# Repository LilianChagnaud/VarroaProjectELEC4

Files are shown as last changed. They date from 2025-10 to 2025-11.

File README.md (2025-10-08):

Projet
2 : comptage de varroa  (effectif : 4)
> sujet existant à compléter :
> https://filesender.renater.fr/?s=download&token=6d0fe1de-e8f5-43eb-b47a-897a4730366f
> - finaliser la partie mécanique
> - valider le choix de la caméra
> - développer la reconnaissance d'image
> - développer l'IHM

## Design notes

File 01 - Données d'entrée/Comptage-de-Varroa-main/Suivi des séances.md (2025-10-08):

### 1ère séance

Au cours de la première séance, nous avons choisi de travailler sur le projet "Comptage de Varroa".
Nous avons entamé la rédaction du cahier des charges pour définir les éléments essentiels du projet.

Afin de visualiser les varroas sur une feuille, nous avons a notre disposition l'ESP32-CAM.
Nous avons alors tenté de visualiser une photo capturée par la caméra de l’ESP32-CAM.
Pour cela, nous avons utilisé le logiciel Arduino IDE pour nous connecter à l’ESP32-CAM.
Nous avons installé Arduino IDE afin de configurer et accéder à la caméra.
Un programme Arduino a été développé pour permettre cette interaction.
La caméra intègre un serveur web, ce qui nous permet de visualiser les photos directement en ligne grâce à l'adresse IP.

Voici le code pour visualiser les photos sur un serveur web : 

```c++
#include "esp_camera.h"
#include <WiFi.h>
#include "WebServer.h"
#include "esp_http_server.h" 

const char* ssid = "Pixel_3581";
const char* password = "12345678910";

#define PWDN_GPIO_NUM 32
#define RESET_GPIO_NUM -1
#define XCLK_GPIO_NUM 0
#define SIOD_GPIO_NUM 26
#define SIOC_GPIO_NUM 27
#define Y9_GPIO_NUM 35
#define Y8_GPIO_NUM 34
#define Y7_GPIO_NUM 39
#define Y6_GPIO_NUM 36
#define Y5_GPIO_NUM 21
#define Y4_GPIO_NUM 19
#define Y3_GPIO_NUM 18
#define Y2_GPIO_NUM 5
#define VSYNC_GPIO_NUM 25
#define HREF_GPIO_NUM 23
#define PCLK_GPIO_NUM 22

void startCameraServer();
void setup() {
Serial.begin(115200);
Serial.setDebugOutput(true);
Serial.println(); 

// Configuration de la caméra
camera_config_t config;
config.ledc_channel = LEDC_CHANNEL_0;
config.ledc_timer = LEDC_TIMER_0;
config.pin_d0 = Y2_GPIO_NUM;
config.pin_d1 = Y3_GPIO_NUM;
config.pin_d2 = Y4_GPIO_NUM;
config.pin_d3 = Y5_GPIO_NUM;
config.pin_d4 = Y6_GPIO_NUM;
config.pin_d5 = Y7_GPIO_NUM;
config.pin_d6 = Y8_GPIO_NUM;
config.pin_d7 = Y9_GPIO_NUM;
config.pin_xclk = XCLK_GPIO_NUM;
config.pin_pclk = PCLK_GPIO_NUM;
config.pin_vsync = VSYNC_GPIO_NUM;
config.pin_href = HREF_GPIO_NUM;
config.pin_sscb_sda = SIOD_GPIO_NUM;
config.pin_sscb_scl = SIOC_GPIO_NUM;
config.pin_pwdn = PWDN_GPIO_NUM;
config.pin_reset = RESET_GPIO_NUM;
config.xclk_freq_hz = 20000000;
config.pixel_format = PIXFORMAT_JPEG;

if(psramFound()){
	config.frame_size = FRAMESIZE_UXGA;
	config.jpeg_quality = 10;
	config.fb_count = 2;
} else {
	config.frame_size = FRAMESIZE_SVGA;
	config.jpeg_quality = 12;
	config.fb_count = 1;
}

// Initialisation de la caméra
esp_err_t err = esp_camera_init(&config);
if (err != ESP_OK) {
	Serial.printf("Échec d'initialisation de la caméra, erreur 0x%x", err);
return;
}

// Connexion Wi-Fi
WiFi.begin(ssid, password);
while (WiFi.status() != WL_CONNECTED) {
	delay(500);
	Serial.print(WiFi.status());
}

Serial.println("");
Serial.println("Connexion Wi-Fi établie");
Serial.print("Adresse IP : ");
Serial.println(WiFi.localIP());

// Démarrage du serveur de caméra
startCameraServer();
Serial.println("Serveur caméra démarré");
}
void loop() {
	delay(10000);
}

// Définition de la fonction startCameraServer et stream_handler
httpd_handle_t stream_httpd = NULL;
static esp_err_t stream_handler(httpd_req_t *req){
camera_fb_t * fb = NULL;
esp_err_t res = ESP_OK;
size_t _jpg_buf_len = 0;
uint8_t * _jpg_buf = NULL;
fb = esp_camera_fb_get();

if (!fb) {
	Serial.println("Échec de capture de la frame");
	httpd_resp_send_500(req);
	return ESP_FAIL;
}

if(fb->format != PIXFORMAT_JPEG){
	bool jpeg_converted = frame2jpg(fb, 80, &_jpg_buf, &_jpg_buf_len);
if(!jpeg_converted){
	Serial.println("Échec de la compression JPEG");
	esp_camera_fb_return(fb);
	httpd_resp_send_500(req);
	return ESP_FAIL;
}

} else {
	_jpg_buf_len = fb->len;
	_jpg_buf = fb->buf;
}

httpd_resp_set_type(req, "image/jpeg");
res = httpd_resp_send(req, (const char *)_jpg_buf, _jpg_buf_len);
if(fb->format != PIXFORMAT_JPEG){
	free(_jpg_buf);
}
	esp_camera_fb_return(fb);
	return res;
}

void startCameraServer(){
	httpd_config_t config = HTTPD_DEFAULT_CONFIG();
	config.server_port = 80;
	httpd_uri_t stream_uri = {
	.uri = "/",
	.method = HTTP_GET,
	.handler = stream_handler,
	.user_ctx = NULL
};

if (httpd_start(&stream_httpd, &config) == ESP_OK) {
	httpd_register_uri_handler(stream_httpd, &stream_uri);
}
}
```

### 2ème séance

Au cours de la deuxième séance, nous avons tenté de faire fonctionner le moteur.
Celui-ci est contrôlé par un microcontrôleur LoRa WiFi et un driver TMC2226.

Nous avons effectué le câblage nécessaire pour assurer la commande du moteur :

-------------------------------------------------------------------------------------------------------------

Câblage Moteur

-------------------------------------------------------------------------------------------------------------

Ainsi que le programme Arduino :

```c++
const int Pas = 18;
const int Dir = 19;

void setup() {
	Serial.begin(115200);
	pinMode(Pas, OUTPUT);
	pinMode(Dir, OUTPUT);
	digitalWrite(Dir, HIGH); // Vous pouvez changer à LOW si vous voulez que le moteur tourne dans l'autre sens
}
void loop() {
	for(int x=0; x<200; x++){
	digitalWrite(Pas, HIGH);
	delayMicroseconds(500); // Ajustez le délai pour contrôler la vitesse
	digitalWrite(Pas, LOW);
	delay(4);
}
delay(1000);
}
```

### 3ème séance

Au cours de la troisième séance, nous travaillons toujours sur le fonctionnement du moteur.
Après avoir constaté un problème avec le driver initial, nous l’avons remplacé par un autre.
Nous avons également opté pour un moteur 12V afin de poursuivre nos essais.
Des tests ont été réalisés avec le driver A4988, mais ils se sont révélés infructueux.
Nous sommes donc revenus à l’utilisation du TMC2226 pour continuer nos essais.

Voici le code pour faire tourner le moteur dans les deux sens :

```c++ 
const int Pas = 3;
const int Dir = 2;
void setup() {
  Serial.begin(115200);
  pinMode(Pas, OUTPUT);
  pinMode(Dir, OUTPUT);
  digitalWrite(Dir, HIGH);
}
void loop() {

  for (int x = 200; x > 0; x--) {
    Serial.println(x);
    digitalWrite(Dir, LOW);
    digitalWrite(Pas, HIGH);
    delayMicroseconds(500);
    digitalWrite(Pas, LOW);
    delay(4);}
 
  for (int x = 0; x < 200; x++) {
    Serial.println(x);    
    digitalWrite(Dir, HIGH);
    digitalWrite(Pas, HIGH);
    delayMicroseconds(500);
    digitalWrite(Pas, LOW);
    delay(4);
  }
  delay(2000);
}
```

### 4ème séance

Après de nombreux essais sur les moteurs, il semble que le problème provienne des alimentations plutôt que du câblage ou du programme.
Le professeur nous a alors suggéré d’utiliser une alimentation 12V via une prise secteur adaptée.

Nous avons ensuite déterminé la hauteur optimale pour positionner la caméra afin d'obtenir une image nette et claire. Cette hauteur est de 24 cm. 

-------------------------------------------------------------------------------------------------------------

Capture d’écran 2024-11-25 à 16 32 52

-------------------------------------------------------------------------------------------------------------

Nous utiliserons cette référence pour créer notre programme 3D.
Pour visualiser le projet, j'ai commencé à créer la conception assistée par ordinateur (CAO) :

-------------------------------------------------------------------------------------------------------------

Capture d’écran 2024-11-25 à 16 59 09

-------------------------------------------------------------------------------------------------------------

### 5ème séance

Au cours de ma cinquième séance de travail, ma priorité était la conception d'un système mécanique de déplacement de caméra en 3D, en utilisant le logiciel de conception assistée par ordinateur Fusion 360. Cela nous permettra d'avoir une vision global du projet, afin de réaliser la partie mécanique de celui-ci.

-------------------------------------------------------------------------------------------------------------

Capture d’écran 2024-11-26 à 11 46 03

-------------------------------------------------------------------------------------------------------------

Le dispositif mécanique que j'ai développé comprend plusieurs éléments :

- Un moteur pas à pas connecté à un axe cylindrique via un coupleur
- Un roulement intégré sur l'axe pour garantir une rotation stable et guidée
- Une transmission du mouvement rotatif permettant le déplacement de la caméra
- Une structure verticale composée de montants supportant l'axe

J'ai stratégiquement positionné les axes à une hauteur de 24 cm, ce qui permet :

- De surélever la caméra au maximum
- D'améliorer la qualité de l'image
- D'élargir significativement le champ de vision

L'axe traversant la structure servira à la fois de guide et de support pour le système de déplacement.

-------------------------------------------------------------------------------------------------------------

Capture d’écran 2024-12-08 à 14 12 38

-------------------------------------------------------------------------------------------------------------

Le dispositif mécanique que j'ai développé comprend plusieurs éléments :

- Un moteur pas à pas connecté à un axe cylindrique via un coupleur
- Un roulement intégré sur l'axe pour garantir une rotation stable et guidée
- Une transmission du mouvement rotatif permettant le déplacement de la caméra
- Une structure verticale composée de montants supportant l'axe

J'ai stratégiquement positionné les axes à une hauteur de 24 cm, ce qui permet :

- De surélever la caméra au maximum
- D'améliorer la qualité de l'image
- D'élargir significativement le champ de vision

-------------------------------------------------------------------------------------------------------------

Capture d’écran 2024-12-08 à 14 14 22

-------------------------------------------------------------------------------------------------------------

L'axe traversant la structure servira à la fois de guide et de support pour le système de déplacement.

-------------------------------------------------------------------------------------------------------------

Capture d’écran 2024-12-08 à 14 06 52

-------------------------------------------------------------------------------------------------------------

Ici, nous observons la section où se situe le support de la caméra. Elle comprend deux supports montés sur des roulements à billes, permettant un mouvement horizontal, ainsi qu’un support également monté sur des roulements à billes, offrant un mouvement vertical.

-------------------------------------------------------------------------------------------------------------

Capture d’écran 2024-12-08 à 14 09 39

-------------------------------------------------------------------------------------------------------------

Suite aux retours de Monsieur Peter et d’un professeur de robotique concernant ma modélisation 3D, plusieurs points d’amélioration ont été soulevés :
- Remplacer le roulement cranté par un roulement à billes.
- Positionner les moteurs du même côté pour faciliter le cheminement des câbles.
- Supprimer le roulement au niveau de la plateforme supportant la caméra et le remplacer par un système de pincement au support.
- Ajouter des guides pour le câblage.
- Réduire l’épaisseur de la plateforme afin de limiter l’inertie et alléger l’ensemble.
- Concevoir des blocs empilables pour les pylônes.
- Remplacer les pièces de glissement des plateformes par des pièces usinées.
- Intégrer des fins de course.

**Remplacer le roulement cranté par un roulement à billes :**

-------------------------------------------------------------------------------------------------------------

Capture d’écran 2024-12-09 à 11 58 18

-------------------------------------------------------------------------------------------------------------

**Moteurs du même coté :**

-------------------------------------------------------------------------------------------------------------

Capture d’écran 2024-12-09 à 11 55 22

-------------------------------------------------------------------------------------------------------------

**Système de pincement :**

-------------------------------------------------------------------------------------------------------------

Capture d’écran 2024-12-09 à 11 59 41

-------------------------------------------------------------------------------------------------------------

**Ajout capteur de fin de course :**

-------------------------------------------------------------------------------------------------------------

Capture d’écran 2024-12-09 à 15 05 34

-------------------------------------------------------------------------------------------------------------

### 6ème séances

Lors de la 6ᵉ séance, j'ai pris les mesures exactes nécessaires pour modéliser les pièces en 3D en vue de leur impression. Pour le moment, les pièces imprimées serviront de prototypes afin de valider les dimensions.

#### Côtes

- [i] Flexible couplings moteur : 18,50 mm de diamètre

- [i] Moteur :
	- [>] Axe moteur : 5 mm
	- [>] Largeur moteur : 42 mm
	- [>] Longueur moteur : 39,5 mm

- [i] Axes profilés :
	- [>] Diamètre 8 mm

- [i] Roulement :
	- [>] Diamètre de 22 mm 

- [i] Support Axes :
	- [>] Longueur : 30 mm
	- [>] Hauteur : 22 mm
	- [>] Largeur : 33,9 mm

- [?] Prévoir support pour fixer le moteur  

#### Impression

- [x] Pylone à gauche du moteur
- [ ] Pylone à droite du moteur
- [ ] Pylone en parallèle du moteur
- [ ] Pylone moteur
- [ ] Support axe moteur 
- [ ] Support axe
- [ ] Support camera

### 7ème séances

Lors de la 7ᵉ séance, j’ai imprimé les prototypes afin de valider les pièces et de pouvoir enfin lancer les impressions finales pour assembler l’ensemble du projet. Les prototypes se sont avérés concluants.







### 8ème séances

Lors de cette séance, j’ai assemblé les prototypes afin de préparer l’impression des pièces finales. J’ai également programmé la gestion des moteurs, en intégrant des capteurs de fin de course et un bouton poussoir permettant d’arrêter le système à tout moment. Après quelques ajustements, j’ai modifié les prototypes pour ajouter les emplacements nécessaires aux capteurs.

Images/Capture d’écran 2025-04-26 à 15.20.42.png

Images/Capture d’écran 2025-04-26 à 15.21.03.png

### 9ème séances

Pendant la 9ᵉ séance, avec Jack, nous avons découpé la plaque de bois qui servira de support pour le système. Nous avons positionné l’ensemble sur la plaque et percé les quatre coins pour installer les supports. Ensuite, nous avons pris différentes mesures entre les piliers pour déterminer les longueurs de profilés à découper. Nous avons également remarqué qu’il était nécessaire de prévoir des fixations supplémentaires sur certaines pièces pour pouvoir attacher correctement les courroies.

Images/Capture d’écran 2025-04-26 à 15.21.19.png

### 10ème séances

Lors de cette séance, j’ai réalisé toutes les modifications 3D nécessaires afin de pouvoir enfin imprimer les pièces et monter le système complet. Un nouveau projet Fusion a aussi été créé pour prendre en compte les cotes réelles du montage.

Images/Capture d’écran 2025-04-26 à 15.21.55.png

### 11ème séances

Durant la 11ᵉ séance, nous avons découpé les profilés à la bonne longueur.

/Users/kylianyacoub/Downloads/Capture d’écran 2025-04-26 à 15.22.17.png

Nous avons ensuite assemblé l’ensemble du système, en effectuant les derniers réglages mécaniques pour tout finaliser.

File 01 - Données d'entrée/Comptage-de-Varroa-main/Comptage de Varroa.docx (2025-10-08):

PROJET : COMPTAGE DE VARROA

Outils à disposition :

- ESP32-CAM
- Support caméra
- Feuille (460-380)
- Moteur pas à pas
- Roulement
- LCD
- Courroies
- Alimentation moteur

https://users.polytech.unice.fr/~pmasson/Enseignement-arduino.htm

https://github.com/makerbase-mks/MKS-StepStick-Driver

Suivie des séances :

1er cours : Nous avons essayé de visualiser une photo prise par la caméra.
Nous nous sommes connectés au ESP32-CAM grâce au logiciel Arduino IDE. Installation de Arduino IDE pour accéder à la caméra du ESP32-CAM. La caméra possède un serveur web ou nous pouvons ainsi visualiser les photos prises par la caméra.

Nous avons également commencé le cahier des charges afin de définir les points importants du projet.

2ème cours :

Cahier des charges : Projet de comptage des varroas

Voici un cahier des charges détaillé pour le projet de comptage des varroas. Ce document formalisera les objectifs, contraintes et besoins spécifiques du projet et servira de référence tout au long de la réalisation.

1. Contexte et objectif

Le varroa est un parasite qui affaiblit les colonies d’abeilles en se nourrissant de leur hémolymphe. Le projet a pour objectif de développer un système de comptage des varroas automatique et à faible coût, basé sur l'utilisation d'une caméra et d'un microcontrôleur ESP32-CAM. Une feuille de papier sera placée sous la ruche pour collecter les varroas qui y tombent. Un système de reconnaissance sera mis en place à l'aide d'une caméra montée sur des axes motorisés, permettant de balayer l'intégralité de la feuille et de détecter les varroas recueillis.

2. Fonctionnalités principales

- Détection et comptage des varroas : Le système doit être capable d’identifier les varroas sur une feuille et de les compter avec précision.
- Stockage ou transmission des données : Les données de comptage doivent être stockées localement ou transmises à une interface utilisateur (application mobile ou web).
- Interface utilisateur : Système simple pour accéder aux résultats du comptage et aux images de la caméra via un LCD.
- Autonomie : Le système doit être économe en énergie pour fonctionner de manière autonome sur de longues périodes.

3. Contraintes techniques

Matériel :

- Utilisation de l’ESP32-CAM pour la capture d'images et l’analyse.
- Caméra capable de capturer des images de haute qualité dans des conditions d'éclairage variables (lumière naturelle et faible éclairage).
- La caméra doit être positionnée à une distance adéquate de la feuille pour capturer clairement les varroas.
- Utilisation d’un LCD qui permettra d’afficher le nombre de varroas sur la feuille

Logiciel :

- Utilisation du logiciel Arduino IDE afin de programmer l’ESP32-CAM
- Interface web intégrée pour accéder au flux vidéo en direct

Budget :

- Coût total limité pour que le système reste abordable pour les apiculteurs amateurs ou professionnels ainsi que les différentes écoles qui voudraient reprendre le projet.
- Utilisation de composants peu coûteux comme l'ESP32-CAM, avec une attention particulière aux options d’alimentation à bas coût.

4. Spécifications techniques

Caméra :

- 5Mpixels.
- Serveur Web pour récupérer les photos.

Microcontrôleur ESP32-CAM :

- Utilisation de la bibliothèque ESP32 pour gérer la caméra.
- Serveur web intégré pour la diffusion d'images en temps réel.
- Connexion Wi-Fi pour l'accès distant.

Algorithme de traitement d'image :

- Détection des objets de petite taille (varroas mesurant environ 1 à 1,5 mm).
- Différenciation entre les varroas et d'autres débris sur la feuille.

5. Étapes de réalisation

Phase 1 :

- Sélection des composants matériels (caméra, ESP32-CAM, alimentation).
- Conception du support pour la caméra (distance, angle, protection contre les intempéries).

Phase 2 :

- Programmation de l’ESP32-CAM pour la capture d’image et le flux vidéo en temps réel.
- Programmation de l’ESP32 afin de démarrer le moteur avec une carte d’alimentation
- Développement de l'algorithme de détection et de comptage des varroas.

Phase 3 :

- Création du support pour la caméra
- Installation des moteurs et des axes
- Installation et programmation du LCD

Phase 4 :

- Tests

6. Critères de réussite

- Précision du comptage des varroas supérieure à 90 %.
- Facilité d’installation et de maintenance pour un apiculteur non-technicien.
- Coût total de production faible

7. Livrables

- Système de comptage des varroas fonctionnel (hardware et software).
- Documentation utilisateur pour l’installation et l’utilisation du système.
- Rapport de tests détaillant les performances du système en conditions réelles.

DATASHEET & SCHEMA :

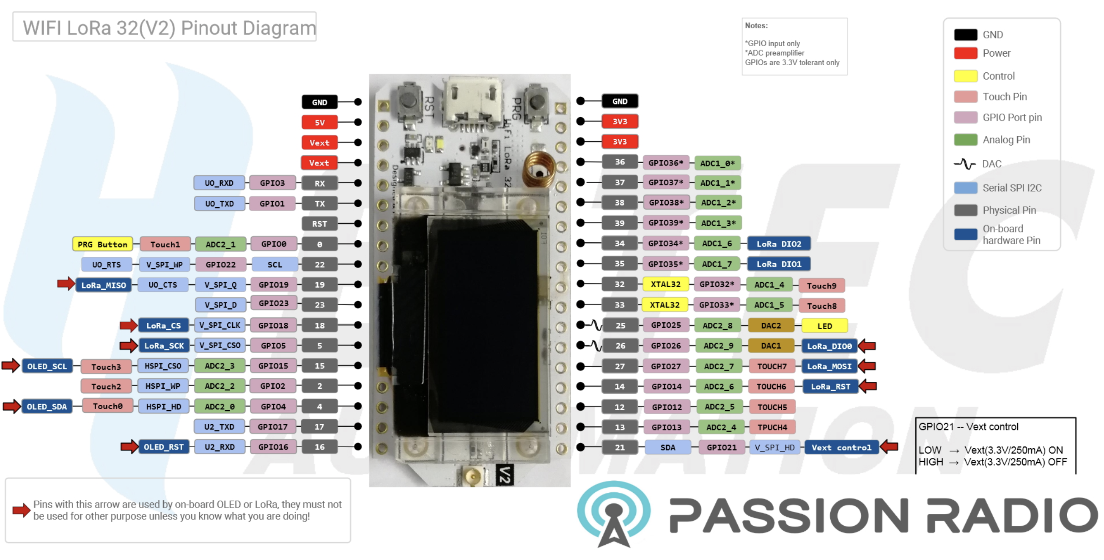
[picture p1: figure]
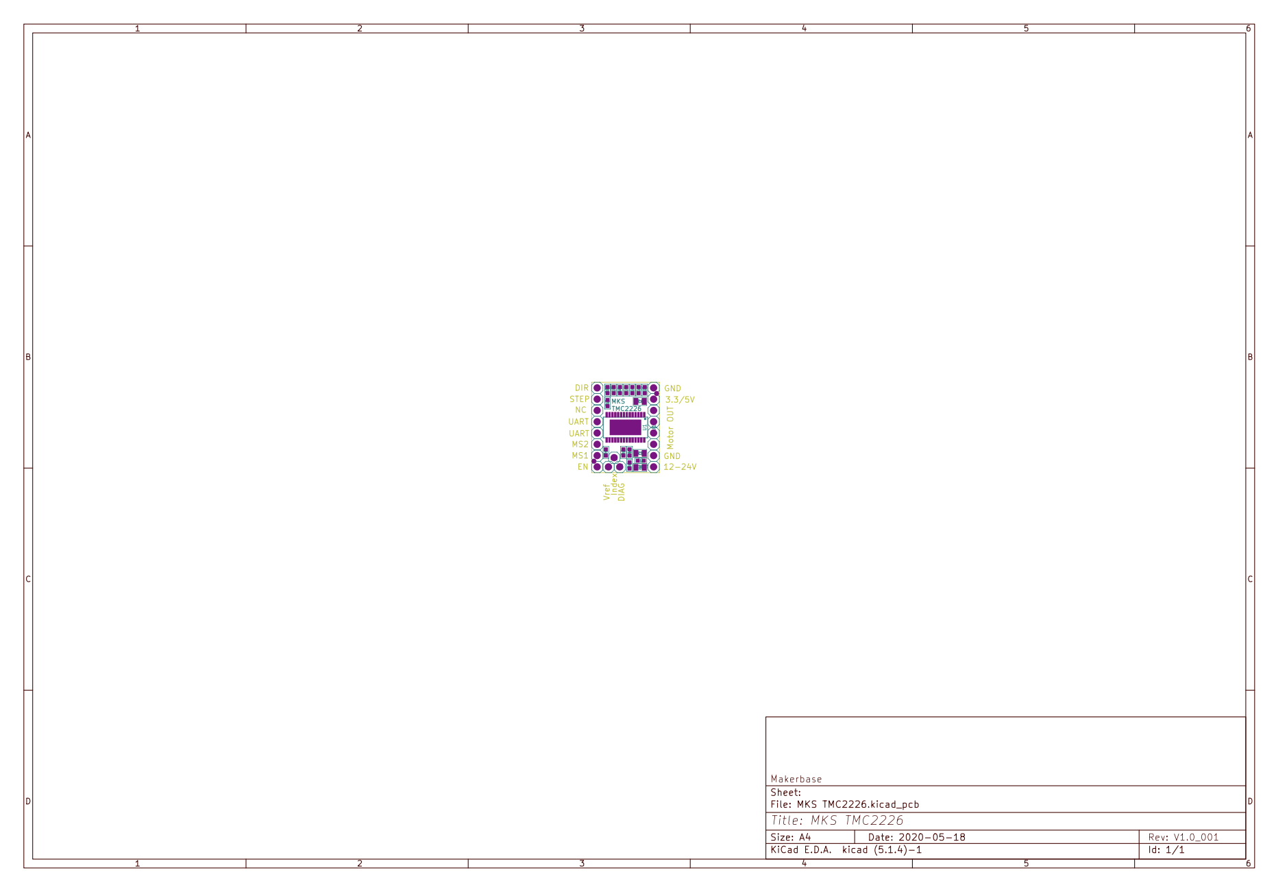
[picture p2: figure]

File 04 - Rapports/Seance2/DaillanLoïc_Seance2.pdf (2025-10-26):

## Rapport Projet Electronique Seance 2

Objectif de la séance :
L’objectif de ma seance portait sur la partie de l’interface graphique. Puisque le but est grâce à cette interface est de pouvoir voir sur un petit écran le nombre de varroa que le système aura compté. En premier lieu d’avoir une vision des différentes solutions réalisables, afin de réaliser de les appliquer et tester pour retenir la plus performante. Durant cette séance, j’ai donc fait un travail de recherche afin de réaliser une interface graphique pour ce projet. La solution actuelle est une page web sur une adresse IP que l’ESP 32 génère, avec une partie logique typeScript pour la logique du code de l’interface, une partie HTML pour la structure, puis pour finir CSS pour le design/ergonomie. Cependant, plusieurs questions surviennent concernant un possible problème de mémoire de l’ESP32. Également si l’ESP32 est capable de réaliser cette solution en plus des différentes tâches afin que le projet final fonctionne suivant les critères du cahier des charges. De plus, concernant l’interface, il est nécessaire de faire quelque chose d’efficace qui correspond au projet. Cependant, il ne faut pas que l’interface soit trop lente en réaction ou autres.
Actuellement, je suis entrain de réaliser un premier prototype de l’interface graphique tout en essayant d’éclaircir les différentes problématiques de cette partie.

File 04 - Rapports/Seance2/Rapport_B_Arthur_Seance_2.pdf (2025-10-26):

Beskororvaynyy Arthur

## Rapport Projet Séance 2 - comptage de varroa

Objectif de la séance :

L’objectif de cette séance était d’explorer et de comprendre le fonctionnement du code Arduino de l’ESP32-CAM. Plus spécifiquement, il s’agissait de trouver une méthode permettant de capturer une image avec l’ESP32 et de pouvoir la transmettre en local, potentiellement via le port série, étant donner qu’on n’a pas le droit d’utiliser de serveur et donc le wifi.
Travaux réalisés :
- Analyse du code Arduino de l’ESP32 – CAM
- Compréhension des librairies et fonctions fournit par Arduino avec l’ESP32 – CAM, pour la capture d’image (i.e. : format, qualité, …).
- Communication série
- J’ai essayé de comprendre comment l’ESP32 CAM MB, pouvait communiquer via le port série.
- Développement d’un script Python de réception
- Dans le but de pouvoir visualiser les images transmises, j’ai essayé de créer un script Python capable de lire le flux série et de reconstruire l’image avec la librairie Pyseries.
Résultats obtenus :
- J’ai réussi à identifier dans le code Arduino, le buffer qui permets la communication série des octets de l’image qui a été prise, et comment prendre une photo avec l’ESP32 – CAM.
- Les codes Arduino et Python, que j’ai réalisé ne sont pas encore concluant, je n’ai pas encore réussi à récupérer tous les octets de données envoyer par l’ESP32 – CAM, ce qui fait que je n’ai pas encore d’image reconstruite non plus. Possible difficultés :
- Il y aura surement un problème de débit concernant la transmission de données via le port série de l’ESP32, donc on devra surement réduire la qualité de l’image, donc possible être amener à faire du filtrage avant de compter les varroas
Prochaines étapes :
- Faire fonctionner la liaisons séries, et obtenir une image pour pouvoir un peu mieux visualiser avec quoi on devra travailler pour pouvoir effectuer le comptage de varroas, et aussi si possible trouver le meilleur compromis entre qualité et débit pour que le transfert ne prenne pas une éternité et que la qualité d’image soit traitable par la suite.

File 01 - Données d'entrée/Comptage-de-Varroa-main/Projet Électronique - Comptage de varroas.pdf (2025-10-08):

## Annexes :

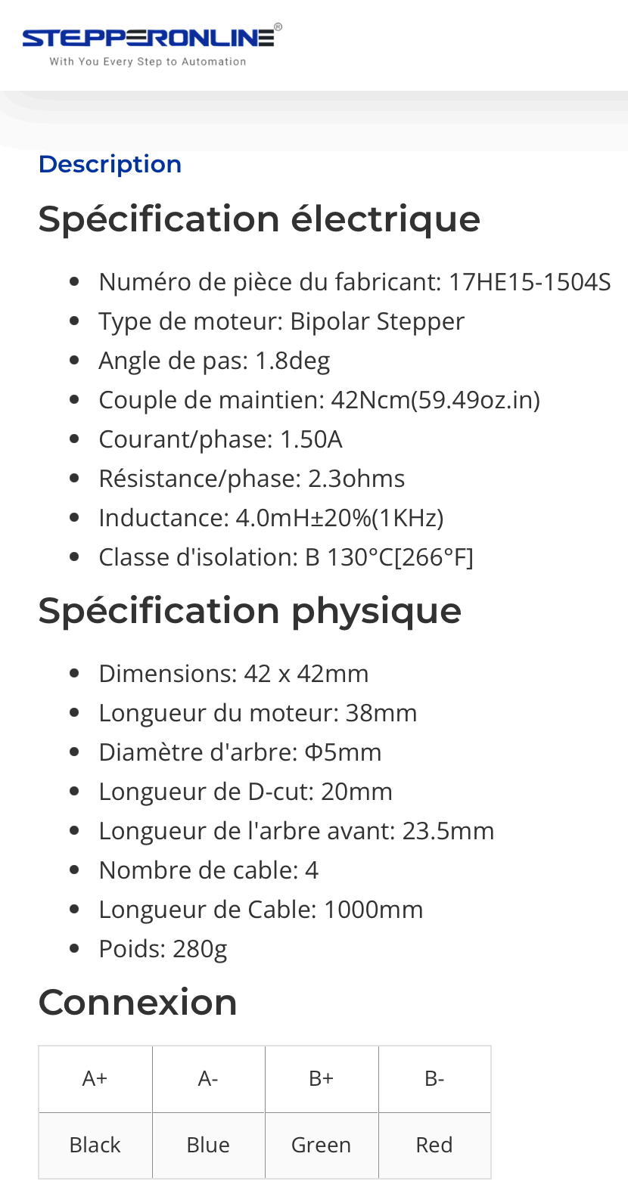
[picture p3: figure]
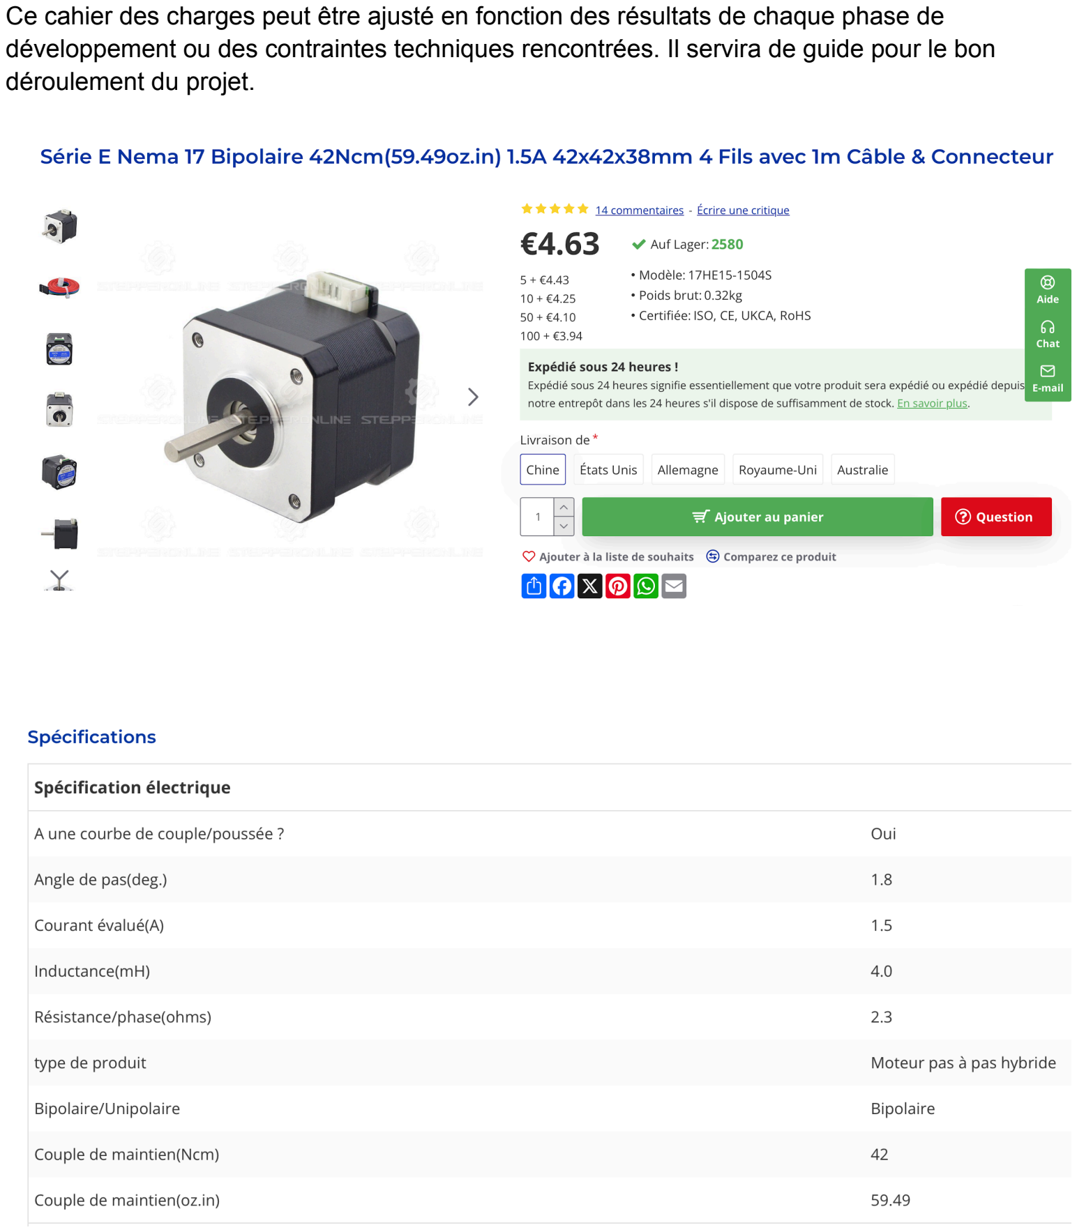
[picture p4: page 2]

Ce cahier des charges peut être ajusté en fonction des résultats de chaque phase de développement ou des contraintes techniques rencontrées. Il servira de guide pour le bon déroulement du projet.

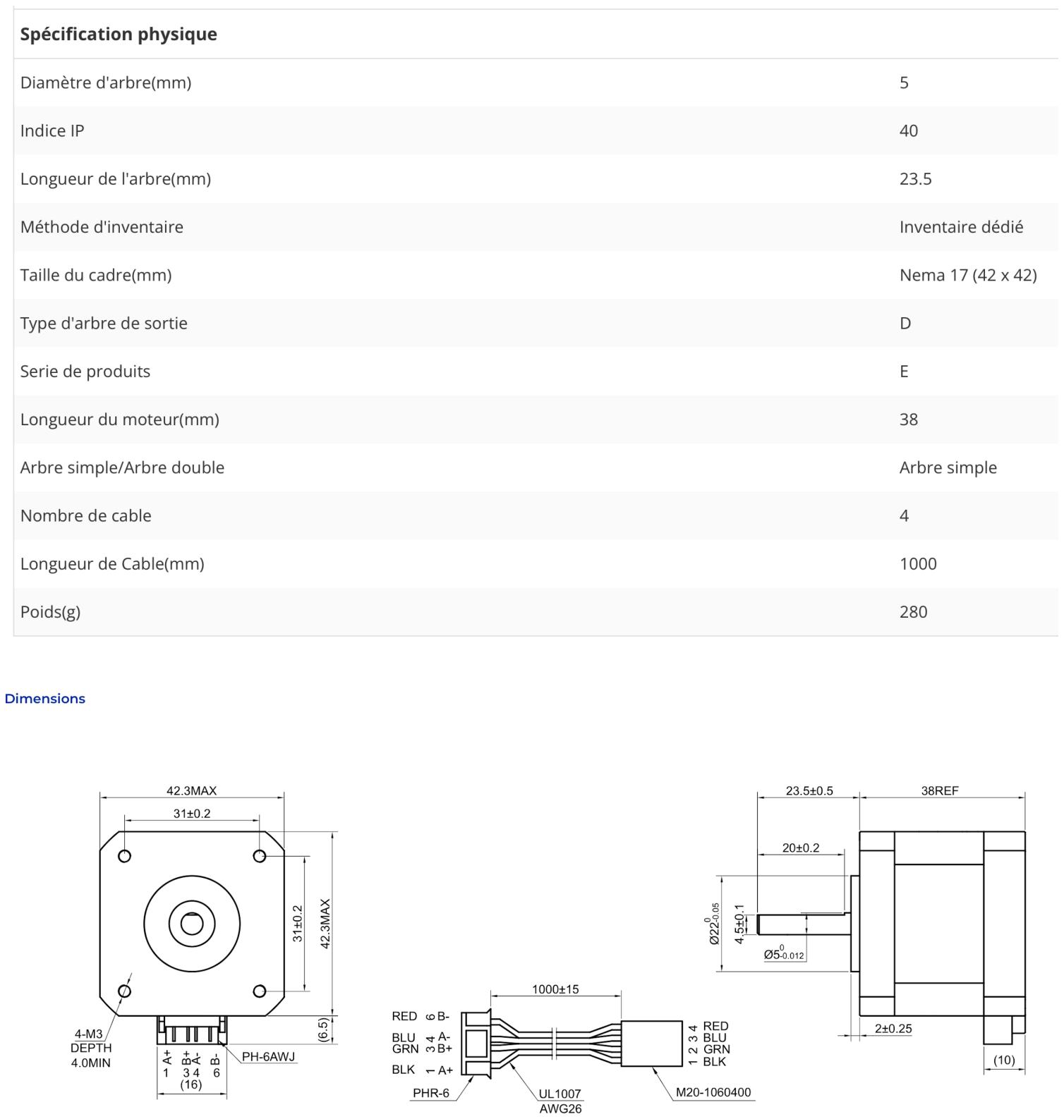
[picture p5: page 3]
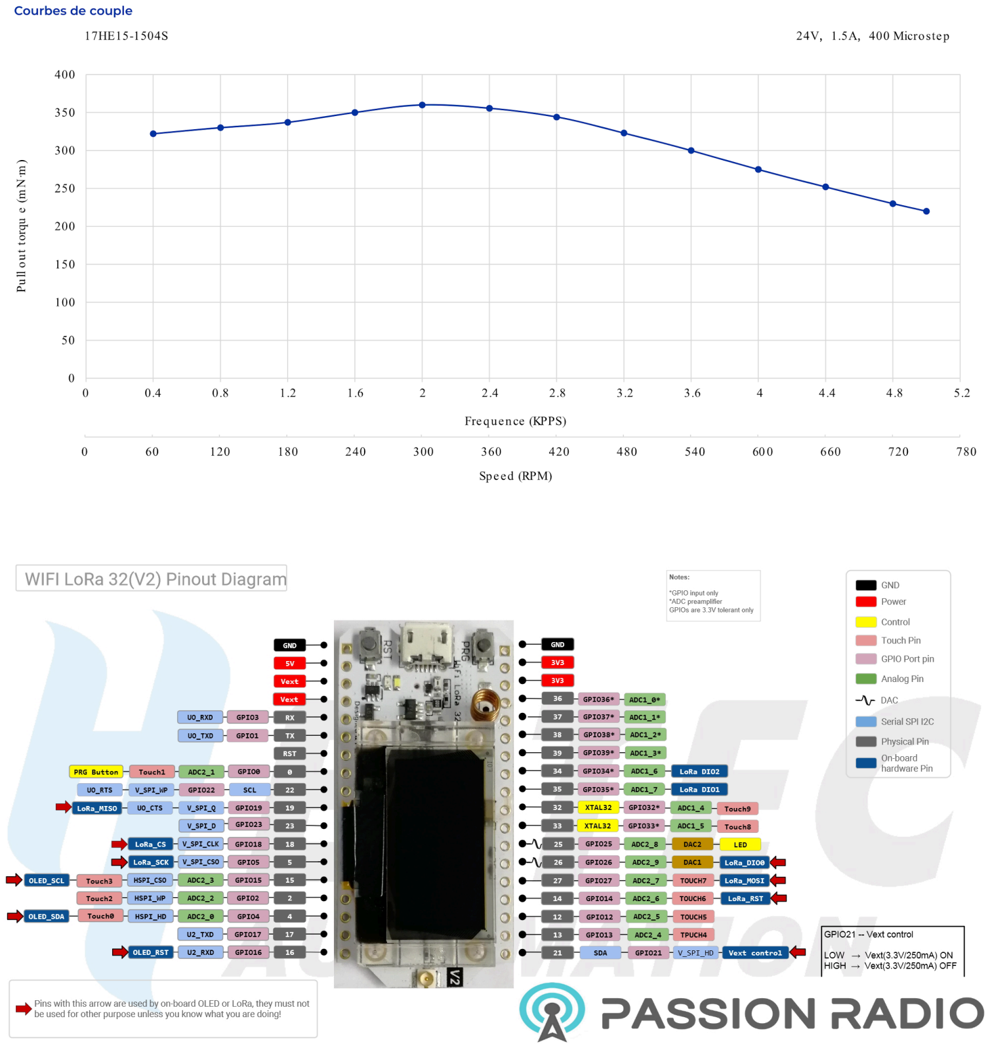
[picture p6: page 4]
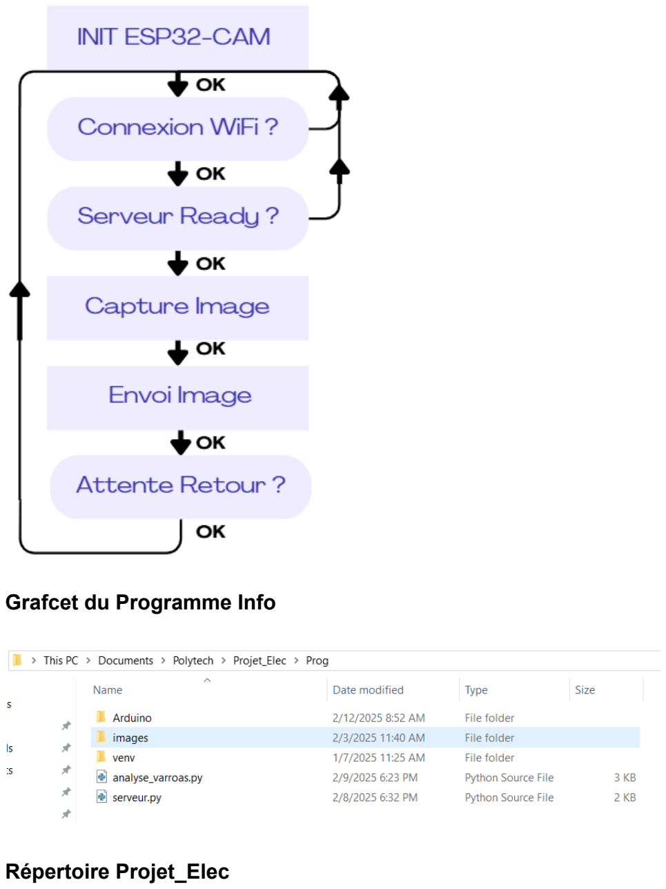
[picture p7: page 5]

## Grafcet du Programme Info

## Répertoire Projet_Elec

## Suivi des séances

## Séance 1- 11 Septembre :

ESP-32 CAM :

On travaille en antenne interne car la résistance est soudée formant une barre oblique

Comment programmer l’ESP32-CAM avec l’Arduino IDE - Tropratik (https://tropratik.fr/programmer-esp32-cam-avec-arduino)

Résolution d’image de 1600x1200

Avancer programme Arduino
Caméra marche
Bonne résolution
Avancée sur 3D et Modélisation

## Séance 2 - 23 Septembre :

En septembre 2024, j’ai débuté mon projet.

- J’ai étudié différentes solutions pour capturer des images des varroas.
- J’ai choisi l’ESP32-CAM comme matériel principal.
- J’ai mis en place mon environnement de développement avec VS Code et un serveur Flask pour recevoir les images.

Premiers tests de capture fonctionnels :

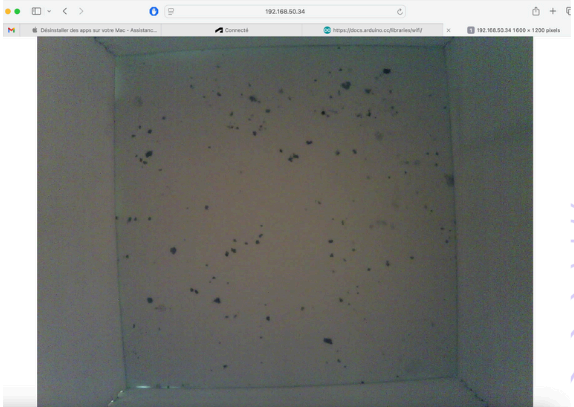
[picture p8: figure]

## Séance 3, 4 et 5 - 12 Novembre au 26 Novembre :

- J’ai mis en place un serveur Flask pour stocker les images.
- J’ai réalisé mes premiers téléversements du code sur l’ESP32-CAM.
- J’ai configuré le réseau Wi-Fi pour envoyer les images au serveur.
- J’ai passé du temps à déboguer les problèmes liés à la connexion série et aux erreurs de téléversement.

## Séance 6 - 9 Décembre:

Développement du traitement d'image

- J’ai développé mon premier script Python avec OpenCV pour détecter les varroas.
- J’ai utilisé une méthode basée sur la conversion en niveaux de gris, la binarisation et la détection de contours.
- J’ai implémenté un comptage automatique des objets détectés.
- J’ai ajouté une fonction de sauvegarde des images annotées.

## Séance 7 - 7 Janvier :

- J’ai identifié et corrigé des erreurs de connexion Wi-Fi.
- J’ai modifié le code pour récupérer correctement l’IP du serveur.
- J’ai dû changer d’ESP32-CAM à cause d’un problème matériel.
- J’ai effectué des tests en conditions réelles sur des images contenant des varroas.

## Séance 8 - 3 Février :

- J’ai rencontré des problèmes de compilation majeurs
- J’ai passé 4 heures à déboguer le problème
- En fin de séance le programme refonctionne comme au début
- Il me reste à avancer sur le fichier analyse de varroas

## Séance 9 - 10 Février :

- Présentation des différents groupes
- Pas d’avancée sur le projet

- J’apprends qu’il faut directement travailler avec un module qui intègre une forme de modèle d’apprentissage intelligent proche de l’intelligence artificielle

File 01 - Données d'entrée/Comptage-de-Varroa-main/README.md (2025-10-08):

# Comptage-de-Varroa
Projet 2ème année électronique : Comptage de Varroa

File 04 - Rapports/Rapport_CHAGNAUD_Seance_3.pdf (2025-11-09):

Rapport Projet – Séance 3
CHAGNAUD Lilian

1

Objectif de la séance :
L’objectif principal de cette séance était de piloter le moteur afin de tester le contrôle de déplacement du système.
Les sous-objectifs étaient :
- Piloter un moteur du banc d’essai.
- Piloter le moteur en indiquant une distance par rapport à l’origine.
- Ajouter des sécurités logicielles dans le code afin d’éviter que le moteur force en butée, en l’absence de fins de course physiques.

Travaux réalisés :
- Pilotage du moteur :
Un premier test de pilotage du moteur a été effectué avec succès. Le moteur a pu être commandé en rotation selon une distance définie par rapport à une position d’origine. L’utilisateur saisi une distance sur l’axe et le moteur positionne le support de caméra a la position souhaité.
- Ajout de sécurités dans le code :
En l’absence de fins de course physiques, des protections ont été ajoutées en dur dans le code afin de stopper automatiquement le moteur lorsque la limite maximale est atteinte. Ces conditions de sécurité permettront d’éviter toute contrainte mécanique ou blocage.

Le code développé au cours de cette séance a été ajouté dans le dépôt, dans le répertoire ProjetElectronique\02 - Travail\Lilian.

Résultats obtenus :
Le moteur a pu être piloté et déplacé sur une distance déterminée, validant ainsi la communication et la commande de base. Les sécurités logicielles ont également été testées et se sont avérées fonctionnelles.
Ces avancées permettent désormais d’envisager le contrôle simultané des deux moteurs.

Difficultés rencontrées :
- Bruit provenant du moteur :
Un bruit inhabituel a été observé lors du pilotage. Après analyse, ce problème provenait d’un mauvais brochage, dû à une différence entre la datasheet et la réalité du câblage du moteur.
- Problème mécanique :
Sur le moteur testé, la roue dentée située à hauteur de l’arbre du moteur ne tournait plus. Ce dysfonctionnement peut-être dû à un mauvais alignement mécanique : une vis de serrage se dévissait progressivement et j’ai revissé ce qui a pu décaler l’axe du moteur

Rapport Projet – Séance 3
CHAGNAUD Lilian

2

par rapport à la roue dentée, empêchant la transmission du mouvement.
De plus, une différence entre la modélisation CAO et la réalisation réelle a été constatée : un écrou manquait, qui semble avoir pour but de lier l’axedu moteur a la roue dentée.

Prochaines étapes :
- Piloter deux moteurs simultanément afin de coordonner leurs mouvements.
- Commencer l’élaboration du code final qui permettra le pilotage complet et synchronisé des deux moteurs, en intégrant les sécurités logicielles et les futures entrées physiques (boutons poussoirs, fins de course, etc.).

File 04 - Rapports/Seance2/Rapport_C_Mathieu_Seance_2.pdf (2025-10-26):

Carré Mathieu

## Rapport Projet Séance 2 – comptage de varroa

## Objectif de la Séance :

L’objectif de cette séance était de définir le cahier des charges du projet. Cette étape permet de définir les tâches prioritaires du projet et également de se séparer le travail plus facilement en découpant le projet selon ses grands axes.
En parallèle de ce travail, l’objectif de la séance était aussi de se renseigner sur les technologies disponibles pour le traitement d’image par IA.

## Cahier Des charges :

Ce projet dispose déjà d’une base. La partie mécanique est notamment bien avancée avec un support pour manipuler la caméra grâce à des moteurs et des capteurs de fin de course montés sur des axes avec des courroies pour déplacer la nacelle de la caméra sur l’axe x et y.

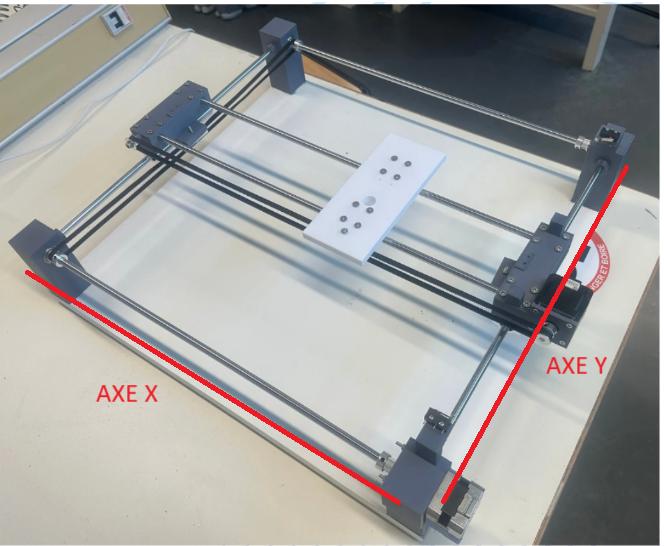
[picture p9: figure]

Les contraintes de ce projet sont :

- Précision de détection du nombre de Varroa : le but principal de ce projet est de compter les Varroa aussi, les plus gros efforts devront être investis dans un algorithme de détection qui possède une marge d’erreur très faible voire inexistante.
- Accessibilité et facilité d’utilisation : Pour compter les Varroa l’utilisateur (l’apiculteur) devra rentrer lui-même les échantillons à analyser. C’est pourquoi une interface simple et compréhensible doit être mise en place pour faciliter le lancement de l’analyse et la compréhension des résultats.
- Autonomie complète : Le projet ne sera pas connecté au réseau ce qui pose une contrainte sur un traitement d’images par serveur distant. Le traitement devra donc être réalisé directement depuis l’électronique présente dans le projet. De plus, cette contrainte oblige à réaliser une interface autonome.

Le temps d’analyse n’est pas une contrainte importante dans le projet. En effet, ce projet doit plus être axé sur la précision que sur la performance. Cependant, le temps d’analyse doit rester acceptable dans le cadre d’une utilisation répétée. Il est
acceptable de se fixer comme temps de détection maximum, un temps de 10 min.

Aux vues des contraintes du projet citées plus haut, 3 grandes parties sont identifiables :

- Algorithme
- Mécanique
- IHM

L’Algorithme concerne tout le traitement d’image nécessaire pour compter les Varroa, mais également le code de déplacement nécessaire pour déplacer la caméra.
La partie mécanique a besoin d’être vérifiée et étudiée pour s’assurer que le travail fait par les étudiants de l’année dernière est fonctionnel. De plus, des modifications peuvent être apportées si nécessaire.
La partie IHM (Interface Homme-Machine), est nécessaire pour faire l’intermédiaire entre l’utilisateur et le projet. Cette interface devra permettre de lancer le comptage de Varroa facilement mais également d’afficher les résultats.

## Diagramme de cas d’utilisation :

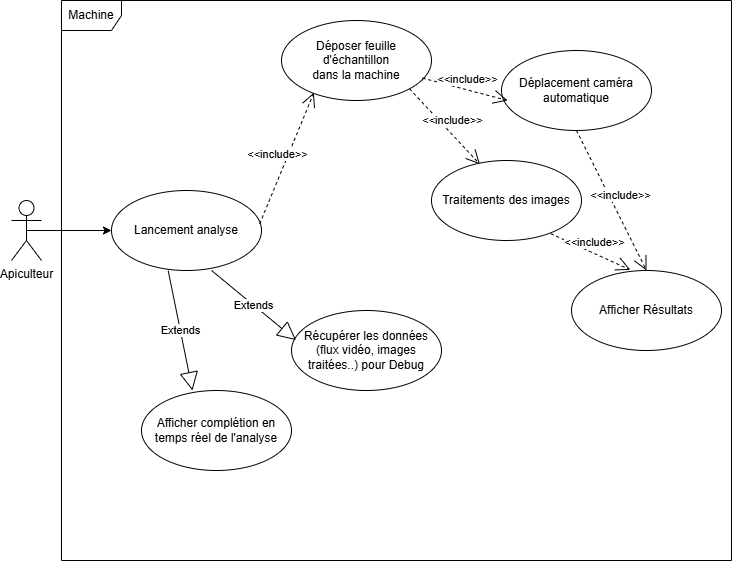
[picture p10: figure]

Les contraintes et objectifs du projet sont synthétisés dans ce diagramme de cas d’utilisation.

## Recherches sur des modèles pour le traitement d’image par

IA :

La contrainte principale qui doit rentrer en compte dans le choix du modèle de Machine Learning est le fait que l’application est en autonomie complète et n’a donc pas accès à un serveur. Ce qui réduit grandement la performance que les modèles peuvent développer. De plus le projet utilise une carte ESP32 qui ne possède que très peu de RAM, la RAM étant le facteur principal de performance dans le traitement d’image.
Aux vues de cette contrainte et après des recherches, un modèle s’est démarqué des autres : TensorFlow Lite

TensorFlow Lite (TFLite) est une version allégée de la bibliothèque TensorFlow, développée par Google, spécialement conçue pour exécuter des modèles d’intelligence artificielle (IA) sur des appareils embarqués et mobiles.
Contrairement à TensorFlow “classique”, qui est souvent utilisé sur des serveurs puissants ou des GPU, TensorFlow Lite est optimisé pour fonctionner sur des dispositifs à faible puissance de calcul
Le modèle est d’abord entraîné avec TensorFlow “classique” sur une machine performante à l’aide de grands ensembles de données puis est converti en un format optimisé grâce au TensorFlow Lite Converter.

## Prochaines étapes :

Approfondir les recherches sur le modèle TensorFlow est faire de premiers tests pour s’assurer que les performances du modèle sont correctes et qu’il sera assez performant pour détecter un objet semblable à un Varroa.
En parallèle, des recherches sur des modèles similaires devront être mises en place pour pouvoir avoir une comparaison entre les différents modèles, pour choisir celui qui correspond le plus aux attentes du projet.

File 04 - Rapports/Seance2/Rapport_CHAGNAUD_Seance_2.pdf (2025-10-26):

Rapport Projet – Séance 2
CHAGNAUD Lilian

1

Objectif de la séance :
L’objectif principal de cette séance était de préparer le pilotage des moteurs qui permettra de déplacer la caméra.

Travaux réalisés :
- Compréhension et analyse :
Lecture des données d’entrée fourni, afin d’identifier la bibliothèque utilisée et la télécharger. Toujours en fonction des données d’entrée mettre en place la maquette de test. Pour ce faire recherche des datasheets des composant utiliser afin de comprendre comment ils se comportent.
- Mise à jour du dépôt Git :
Ajout d’un sous-dossier Datasheet contenant les fiches techniques. Ces documents permettront de mieux comprendre les caractéristiques électriques et mécaniques des moteurs utilisés, ainsi que les contraintes de commande associées.
- Récupération et analyse du code de contrôle moteur :
Le code fourni dans les données d’entrée ne correspondait pas à celui déjà implémenté dans l’ESP32.
- Tentative de pilotage moteur :
Une première tentative de pilotage a été réalisée, mais sans succès. Après analyse, il s’est avéré que la référence du microcontrôleur fournie n’était pas la bonne, et que le brochage différait entre la version V1 et la version V2 de l’ESP32. Cette incompatibilité empêchait le code de s’exécuter correctement.

Résultats obtenus :
À ce stade, le moteur n’a pas encore pu être piloté en raison des problèmes de compatibilité entre les versions de l’ESP32. Cependant, la structure logicielle et les ressources nécessaires sont désormais bien organisées (Git mis à jour, datasheets disponibles, code récupéré et analysé), ce qui facilitera la poursuite du développement lors de la prochaine séance.

Difficultés rencontrées :
- Différences de brochage entre les versions V1 et V2 de l’ESP32, empêchant l’exécution correcte du code.
- Code préexistant non conforme à celui fourni dans les données d’entrée.

Rapport Projet – Séance 2
CHAGNAUD Lilian

2

Prochaines étapes :
- Corriger le code afin d’adapter le brochage à la version actuelle de l’ESP32.
- Parvenir au pilotage fonctionnel du moteur.
- Ajouter des accessoires complémentaires tels que les boutons poussoirs et les fins de course.
- Mettre en place un squelette de programme permettant le contrôle des deux moteurs en parallèle.

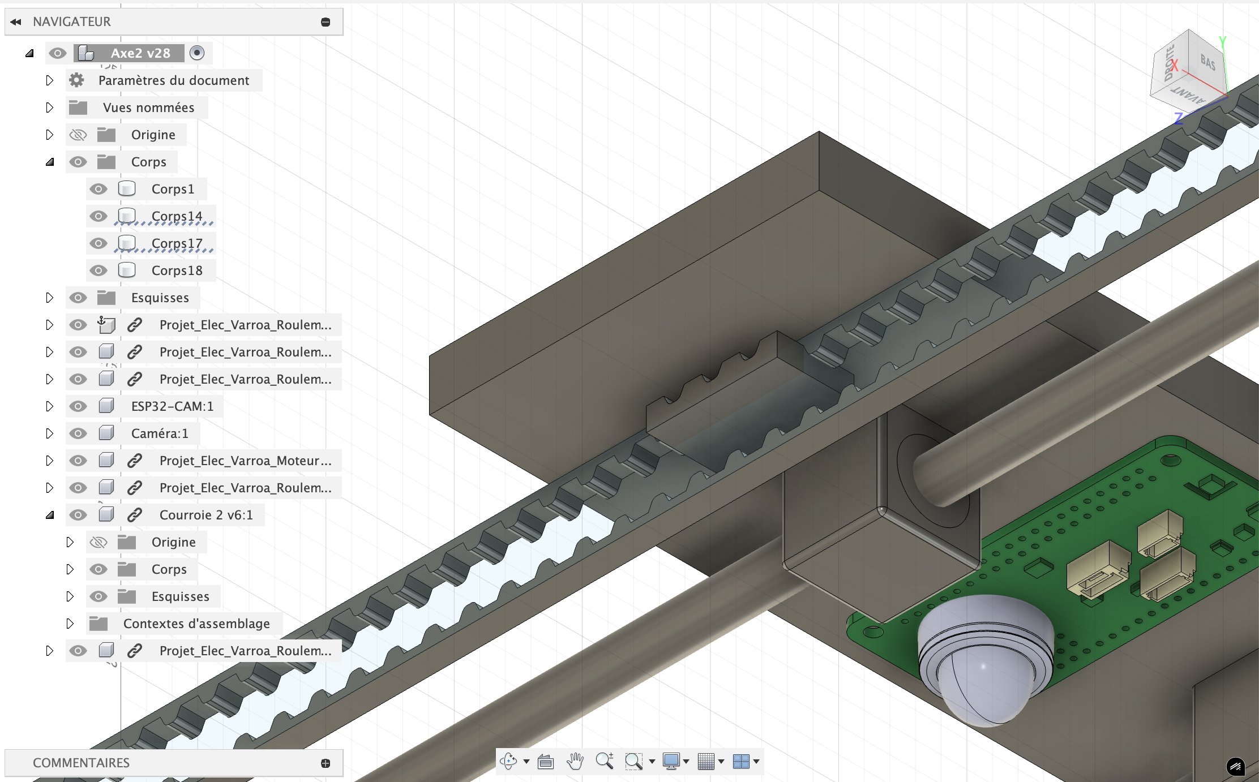
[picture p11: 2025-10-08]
01 - Données d'entrée/Comptage-de-Varroa-main/Images/Capture d’écran 2024-12-09 à 11.59.41.png

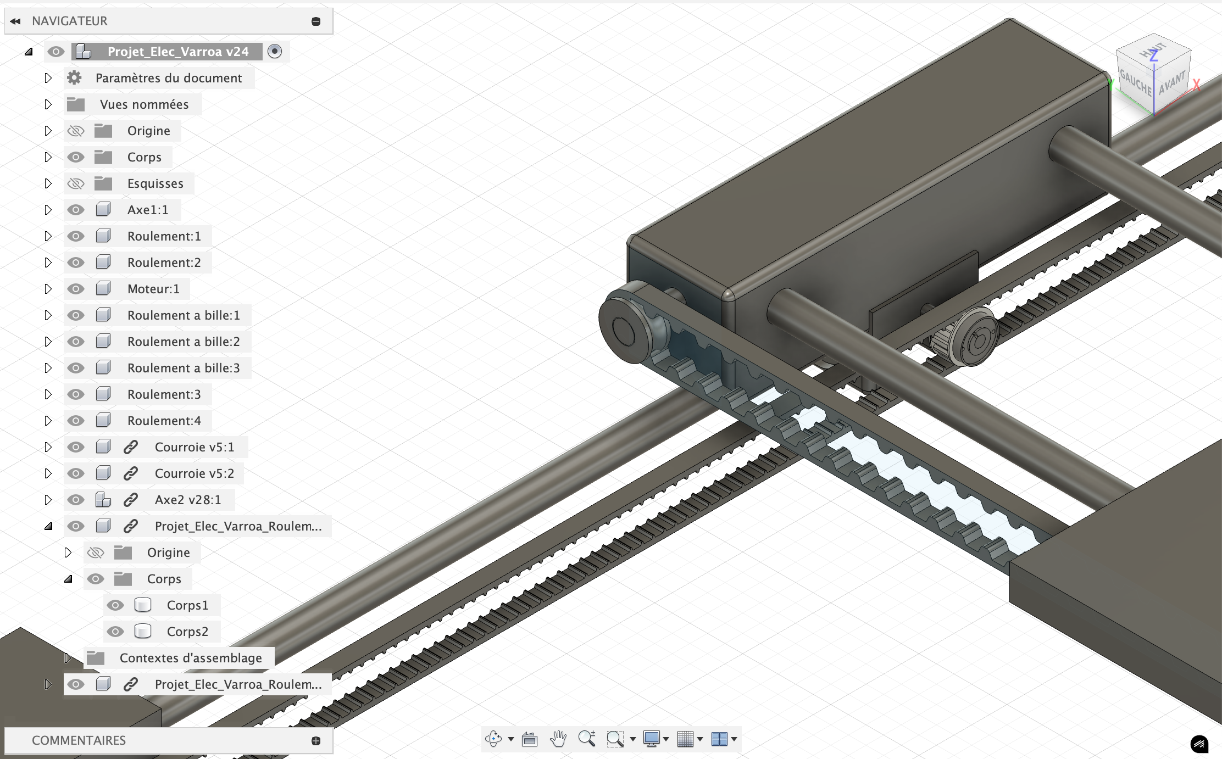
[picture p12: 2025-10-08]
01 - Données d'entrée/Comptage-de-Varroa-main/Images/Capture d’écran 2024-12-09 à 11.58.18.png

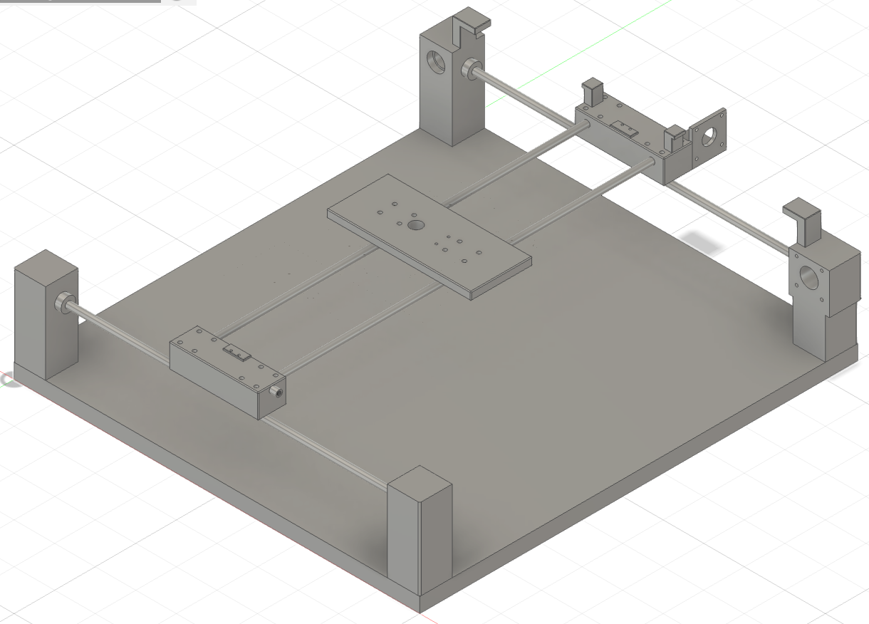
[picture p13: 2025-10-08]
01 - Données d'entrée/Comptage-de-Varroa-main/Images/Capture d’écran 2025-04-26 à 15.21.55.png

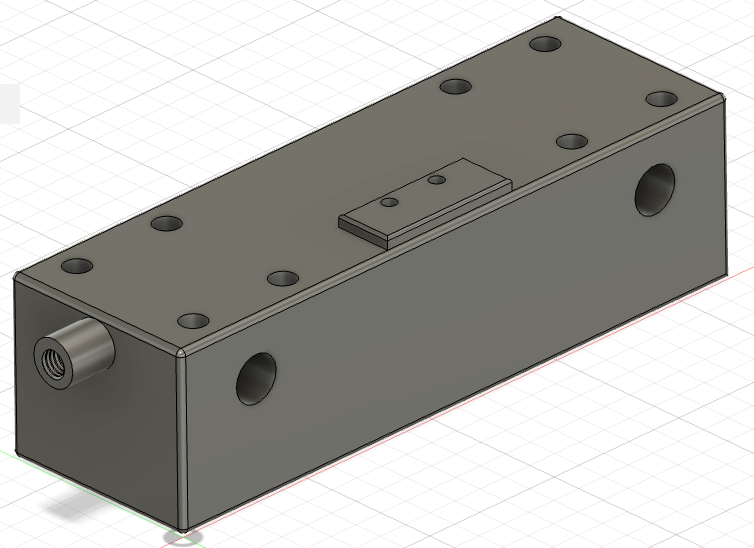
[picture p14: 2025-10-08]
01 - Données d'entrée/Comptage-de-Varroa-main/Images/Capture d’écran 2025-04-26 à 15.21.19.png

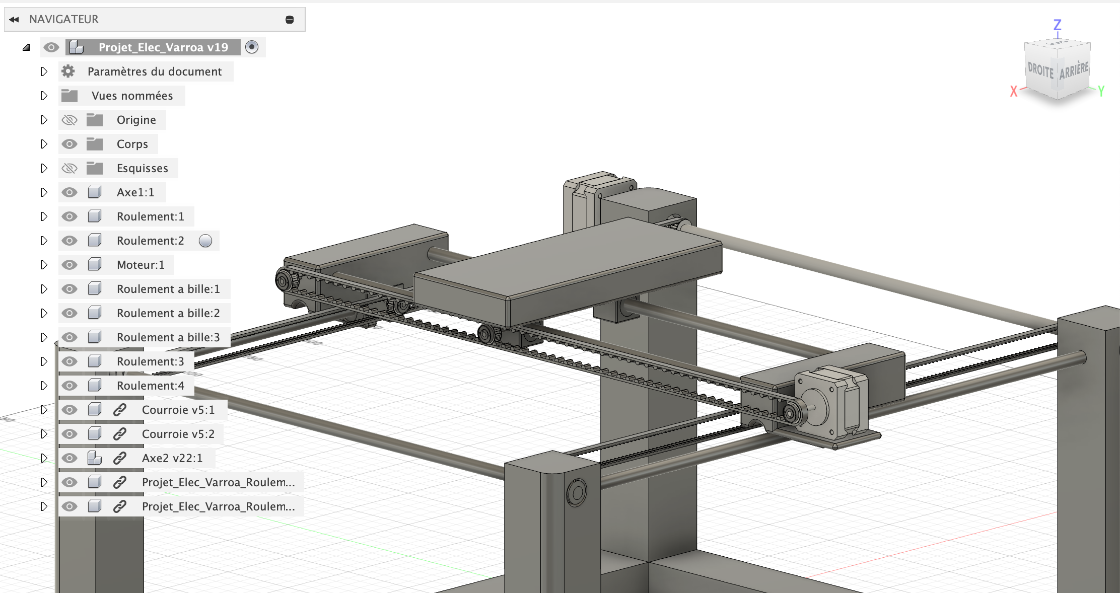
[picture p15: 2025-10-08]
01 - Données d'entrée/Comptage-de-Varroa-main/Images/Capture d’écran 2024-12-08 à 14.14.22.png

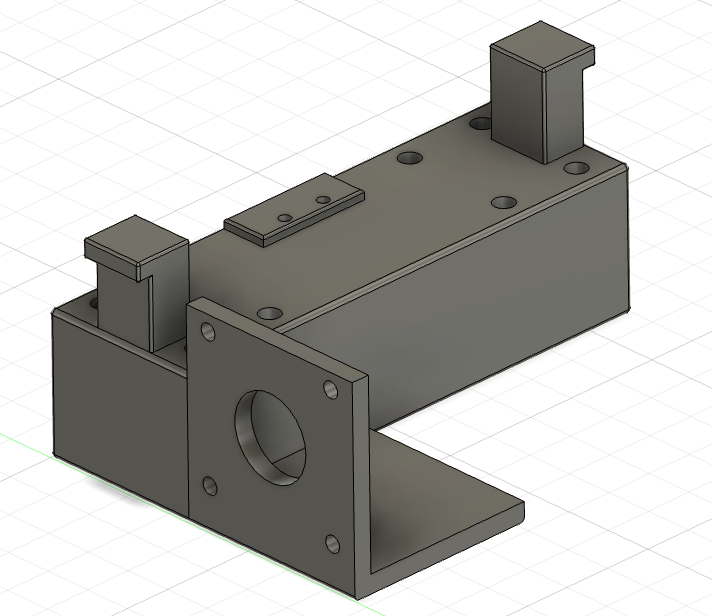
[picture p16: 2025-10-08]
01 - Données d'entrée/Comptage-de-Varroa-main/Images/Capture d’écran 2025-04-26 à 15.21.03.png

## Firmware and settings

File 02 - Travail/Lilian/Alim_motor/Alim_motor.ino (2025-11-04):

#include <AccelStepper.h>

#define dirPin 12
#define stepPin 13

AccelStepper stepper(AccelStepper::DRIVER, stepPin, dirPin);

// === PARAMÈTRES MECANIQUES ===
const float stepsPerMM = 40.0; // 1 tour moteur(1600 pas) équivaut à 40mm
const float offsetMin = 35.0; // Distance entre le bord de la planche et la limite de translation du support de caméra en mm
const float offsetMax = 45.0;
const float cameraSupportLength = 75.0;
const float totalLength = 540.0; // longueur de la planche en mm
const float usableLength = totalLength - offsetMin - offsetMax - cameraSupportLength; //383mm
const float minPos = 0; // Position niveau moteur en mm
const float maxPos = usableLength;

// === PARAMÈTRES MOTEUR ===
//const int stepsPerRevolution = 1600; // 1 tour moteur = 1600 pas (en 1/8 microstep)
const int speed = 1500;              // vitesse max (pas/s)
const int accel = 1000;               // accélération (pas/s²)

void setup() {
  Serial.begin(9600);
  stepper.setMaxSpeed(speed);
  stepper.setAcceleration(accel);
  stepper.setCurrentPosition(0);

  Serial.println("Prêt. Entrez une position entre 0 et 383mm :");
}

void loop() {
  if(Serial.available() > 0){
    float targetMM = Serial.parseFloat();

    while (Serial.available() > 0) Serial.read(); // vide le buffer pour les \n et \r

    if (targetMM < minPos) targetMM = minPos;
    if (targetMM > maxPos) targetMM = maxPos;

    long targetSteps = targetMM * stepsPerMM;
    stepper.moveTo(targetSteps);

    Serial.print("Deplacement vers ");
    Serial.print(targetMM);
    Serial.println(" mm ...");

  }
  stepper.run();
}

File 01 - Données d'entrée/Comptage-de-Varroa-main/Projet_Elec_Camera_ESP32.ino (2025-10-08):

#include "esp_camera.h"
#include <WiFi.h>
#include "WebServer.h"
#include "esp_http_server.h"
#include <HTTPClient.h>
#include "soc/soc.h"
#include "soc/rtc_cntl_reg.h"

const char* ssid = "Pixel_3581"; //Redmi Note 10 5G //Pixel_3581
const char* password = "1234567891011"; //3ee7230b //12345678910
bool captureEnabled = true; // Indique si la capture d'images est activée

#define PWDN_GPIO_NUM 32
#define RESET_GPIO_NUM -1
#define XCLK_GPIO_NUM 0
#define SIOD_GPIO_NUM 26
#define SIOC_GPIO_NUM 27
#define Y9_GPIO_NUM 35
#define Y8_GPIO_NUM 34
#define Y7_GPIO_NUM 39
#define Y6_GPIO_NUM 36
#define Y5_GPIO_NUM 21
#define Y4_GPIO_NUM 19
#define Y3_GPIO_NUM 18
#define Y2_GPIO_NUM 5
#define VSYNC_GPIO_NUM 25
#define HREF_GPIO_NUM 23
#define PCLK_GPIO_NUM 22

void startCameraServer();
void setup()
{
  // Désactive le watchdog matériel (pour débogage)
  WRITE_PERI_REG(RTC_CNTL_BROWN_OUT_REG, 0);
  Serial.begin(115200);
  Serial.println("\n===== DÉMARRAGE ESP32-CAM =====");

  // Vérification PSRAM
  if (!psramFound()) {
    Serial.println("ERREUR : PSRAM non détectée !");
    while (1); // Bloque si pas de PSRAM
  }
  else {
    Serial.println("PSRAM détectée.");
  }

  Serial.setDebugOutput(true);
  Serial.println();

  // Instructions pour le contrôle
  Serial.println("Tapez 'start' pour démarrer et 'stop' pour arrêter la capture.");

  // Configuration de la caméra
  camera_config_t config;
  config.ledc_channel = LEDC_CHANNEL_0;
  config.ledc_timer = LEDC_TIMER_0;
  config.pin_d0 = Y2_GPIO_NUM;
  config.pin_d1 = Y3_GPIO_NUM;
  config.pin_d2 = Y4_GPIO_NUM;
  config.pin_d3 = Y5_GPIO_NUM;
  config.pin_d4 = Y6_GPIO_NUM;
  config.pin_d5 = Y7_GPIO_NUM;
  config.pin_d6 = Y8_GPIO_NUM;
  config.pin_d7 = Y9_GPIO_NUM;
  config.pin_xclk = XCLK_GPIO_NUM;
  config.pin_pclk = PCLK_GPIO_NUM;
  config.pin_vsync = VSYNC_GPIO_NUM;
  config.pin_href = HREF_GPIO_NUM;
  config.pin_sscb_sda = SIOD_GPIO_NUM;
  config.pin_sscb_scl = SIOC_GPIO_NUM;
  config.pin_pwdn = PWDN_GPIO_NUM;
  config.pin_reset = RESET_GPIO_NUM;
  config.xclk_freq_hz = 20000000;
  config.pixel_format = PIXFORMAT_JPEG;

  if(psramFound())
  {
  config.frame_size = FRAMESIZE_UXGA;
  config.jpeg_quality = 10;
  config.fb_count = 2;
  }
  
  else
  {
  config.frame_size = FRAMESIZE_SVGA;
  config.jpeg_quality = 12;
  config.fb_count = 1;
  }

  // Initialisation de la caméra
  esp_err_t err = esp_camera_init(&config);
  if (err != ESP_OK)
  {
  Serial.printf("Échec d'initialisation de la caméra, erreur 0x%x", err);
  return;
  }

  WiFi.setAutoReconnect(true);
  WiFi.persistent(true);
  Serial.printf("Connexion à %s...\n", ssid);
  WiFi.begin(ssid, password);

  while (WiFi.status() != WL_CONNECTED) {
    delay(500);
    Serial.print(".");
  }
  Serial.println("\nWiFi connecté !");

  // Connexion Wi-Fi
  WiFi.begin(ssid, password);
  while (WiFi.status() != WL_CONNECTED)
  {
  delay(500);
  Serial.print(WiFi.status());
  }

  Serial.println("");
  Serial.println("Connexion Wi-Fi établie");
  Serial.print("Adresse IP : ");
  Serial.println(WiFi.localIP());

  // Démarrage du serveur de caméra
  startCameraServer();
  Serial.println("Serveur caméra démarré");
}
  
void loop() {
    // Vérifiez les commandes dans le Moniteur série
    if (Serial.available()) {
        String command = Serial.readStringUntil('\n'); // Lire jusqu'à la fin de ligne
        command.trim(); // Supprime les espaces et sauts de ligne

        if (command == "start") {
            captureEnabled = true;
            Serial.println("Capture démarrée !");
        } else if (command == "stop") {
            captureEnabled = false;
            Serial.println("Capture arrêtée !");
        } else {
            Serial.println("Commande non reconnue. Tapez 'start' ou 'stop'.");
        }
    }

    // Capture et envoi d'images uniquement si activé
    if (captureEnabled) {
        sendToServer();
        delay(10000); // Temps entre deux captures
    } else {
        delay(100); // Petite pause pour ne pas surcharger la boucle
    }
}

// Définition de la fonction startCameraServer et stream_handler
httpd_handle_t stream_httpd = NULL;
static esp_err_t stream_handler(httpd_req_t *req)
{
  camera_fb_t * fb = NULL;
  esp_err_t res = ESP_OK;
  size_t _jpg_buf_len = 0;
  uint8_t * _jpg_buf = NULL;
  fb = esp_camera_fb_get();

  if (!fb)
  {
    Serial.println("Échec de capture de la frame");
    httpd_resp_send_500(req);
    return ESP_FAIL;
  }

  if(fb->format != PIXFORMAT_JPEG)
  {
    bool jpeg_converted = frame2jpg(fb, 80, &_jpg_buf, &_jpg_buf_len);
    if(!jpeg_converted)
    {
      Serial.println("Échec de la compression JPEG");
      esp_camera_fb_return(fb);
      httpd_resp_send_500(req);
      return ESP_FAIL;
    }
  } 

  else 
  {
    _jpg_buf_len = fb->len;
    _jpg_buf = fb->buf;
  }

  httpd_resp_set_type(req, "image/jpeg");
  res = httpd_resp_send(req, (const char *)_jpg_buf, _jpg_buf_len);
  if(fb->format != PIXFORMAT_JPEG)
  {
    free(_jpg_buf);
  }
  esp_camera_fb_return(fb);
  return res;
}

void startCameraServer()
{
  httpd_config_t config = HTTPD_DEFAULT_CONFIG();
  config.server_port = 80;
  httpd_uri_t stream_uri = {
  .uri = "/",
  .method = HTTP_GET,
  .handler = stream_handler,
  .user_ctx = NULL
  };

  if (httpd_start(&stream_httpd, &config) == ESP_OK)
  {
    httpd_register_uri_handler(stream_httpd, &stream_uri);
  }
}

void sendToServer()
{
    // Capture de l'image
    camera_fb_t * fb = esp_camera_fb_get();
    if (!fb) {
        Serial.println("Échec de capture de la frame");
        return;
    }

    // Configurer le client HTTP
    HTTPClient http;
    http.begin("http://10.212.100.215:5000/upload"); // Remplacez par l'URL de votre serveur
    http.addHeader("Content-Type", "image/jpeg");

    // Envoyer l'image via HTTP POST
    int httpResponseCode = http.POST(fb->buf, fb->len);
    if (httpResponseCode > 0) {
        Serial.printf("Réponse serveur : %d\n", httpResponseCode);
    } else {
        Serial.printf("Erreur HTTP : %s\n", http.errorToString(httpResponseCode).c_str());
    }

    http.end();
    esp_camera_fb_return(fb); // Libérer la mémoire
}

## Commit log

2025-10-08 Add correct input data
    [PCB_bee.GBL, PCB_bee.GBO, PCB_bee.GBP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]
2025-10-23 Add Motor Datasheets
2025-10-26 Add report + move motor code in working space
2025-11-04 Code working for controling motor
2025-11-04 Code working for controling top motor with command
